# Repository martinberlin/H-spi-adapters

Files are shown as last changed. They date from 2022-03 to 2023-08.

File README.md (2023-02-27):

## Small SPI adapters

H stands for Hardware.

In this repository we will keep PCB designs done in KiCAD for SPI adapters we use. This PCB hardware work uses the [CERN Open Hardware Licence Version 2](https://github.com/martinberlin/H-spi-adapters/blob/master/LICENSE) in the weakly reciprocal version.
Be aware that this is experimental work mostly done for research and **mass-producing this PCB's is not permitted without our written consent**. Fabricating and selling hardware also implies that you need to provide support / fixes and maintain your code examples up to date.

### ESP32-C3 24 pin Good-Display epaper controller with touch

Latest versions of this PCB idea are moved to the [Bistable-smart-switch repository](https://github.com/martinberlin/bistable-smart-switch). Will leave this initial version here for historic reasons.
Along with the 220AC-3.3DC converter with Latch relay this PCB can be used to make a light wall switch but is also great to experiment with SPI epapers and UX design. Here a preview showing front and back Cooper layers plus 3D view:

Fr cu

Back cu

Silkscreen

3D-view

This PCB will be offered only in our [Lectronz store](https://lectronz.com/stores/fasani/). Last unit is available only till end of February 2023.

### UC8156 SPI adapter for Tinypico

Beginning of 2022 I started to learn KiCAD and get more into Hardware. My intention is to help people with their own projects and make new versions, first of existing adapters, to make them smaller and optimize certain things that, I think, could be make better.

My first product in this direction is the [Tinypico SPI adapter for UC8156 displays](https://www.tindie.com/products/fasani/tinypico-small-uc8156-epaper-hat).

uc8156-adapter-small

The supported [displays are sold by German company PlasticLogic](https://www.plasticlogic.com/sampleshop).

## Goodisplay SPI adapter

This is currently being designed. There is a 3 pad's jumper in the PCB, this is what they called RESE option, different epapers might need either the 4.7 soldered to the center, others the 3. If this is wrong selected the epaper might fail to refresh.
Please check what is the right choice for your model downloading the [DESPI-co2 datasheet](https://www.good-display.com/companyfile/DESPI-C02-Specification-29.html).

## Other SPI adapters that might come

Goodisplay Tinypico ESP32 HAT (Idea) In Production, needs revisions from a higher hierarchie ;)

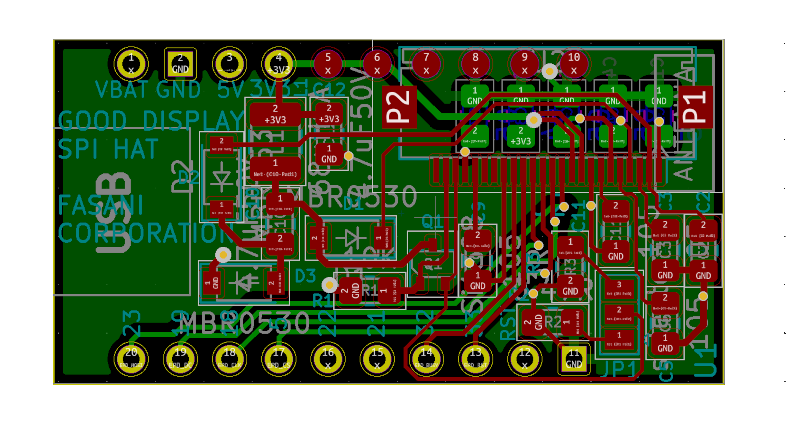
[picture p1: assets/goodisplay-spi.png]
Good display Tinypico HAT


Other epapers.

Intention to make a mini-parallel epaper driver (Will be super hard design)

For more information and currect projects please check:

[https://fasani.de/pcb-design-projects](https://fasani.de/pcb-design-projects)
Most of the PCB's where designed using latest version of KiCAD when writing this lines ( V. 6 )

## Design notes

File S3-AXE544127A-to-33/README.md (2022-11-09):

## Panasonic AXE544127A connector to a 33 pin FPC epaper connector

[AXE544127A](https://app.ultralibrarian.com/details/195de4da-7296-11e9-ab3a-0a3560a4cccc/Panasonic/AXE544127A) to a **XF2M-3315-1A** 33 pin connector which corresponds to 9.7" epaper displays (ED097OC4, ED097TCx and more)

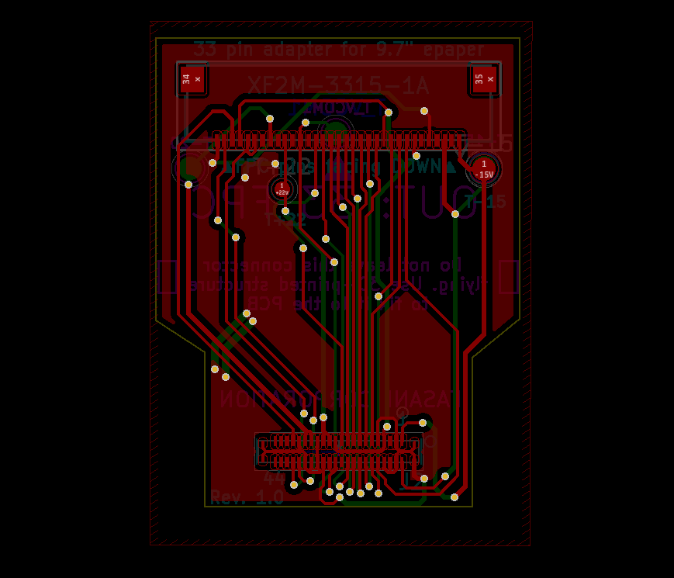
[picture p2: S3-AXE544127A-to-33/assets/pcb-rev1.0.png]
pcb F.Cu


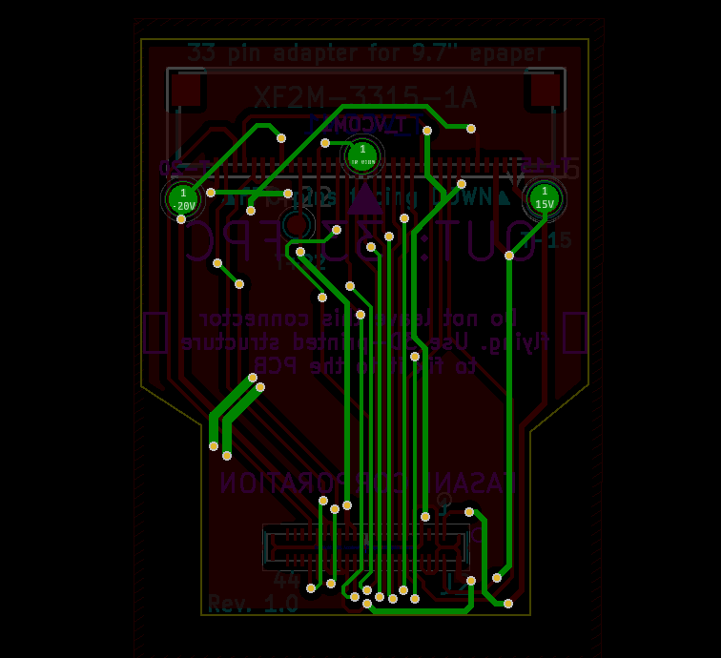
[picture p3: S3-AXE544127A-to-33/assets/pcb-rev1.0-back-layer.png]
pcb Back Cu layer


In short: The aim of this adapter is to use a cheap Lilygo S3 board with all it's hardware additions (RTC, ESP32S3 with fast PSRAM and others) to power a much bigger display than the EPD047.

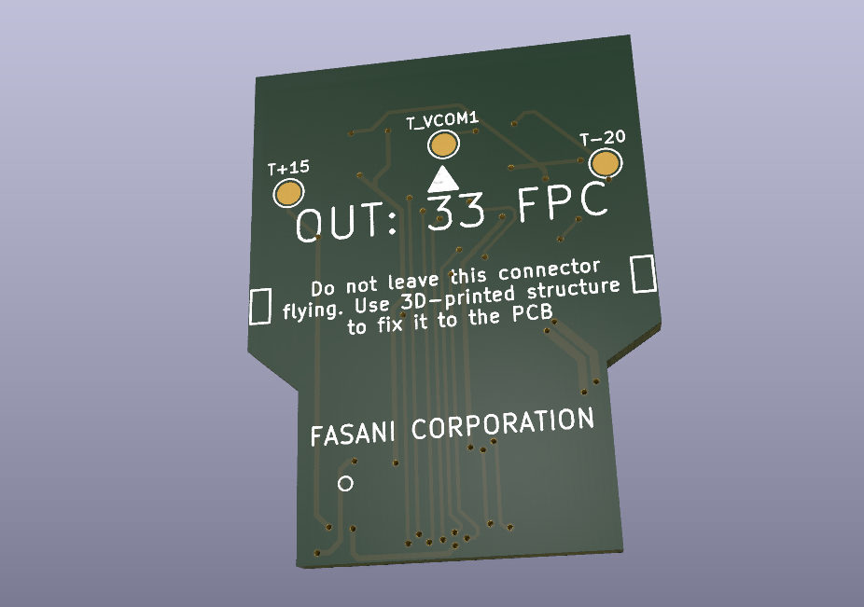
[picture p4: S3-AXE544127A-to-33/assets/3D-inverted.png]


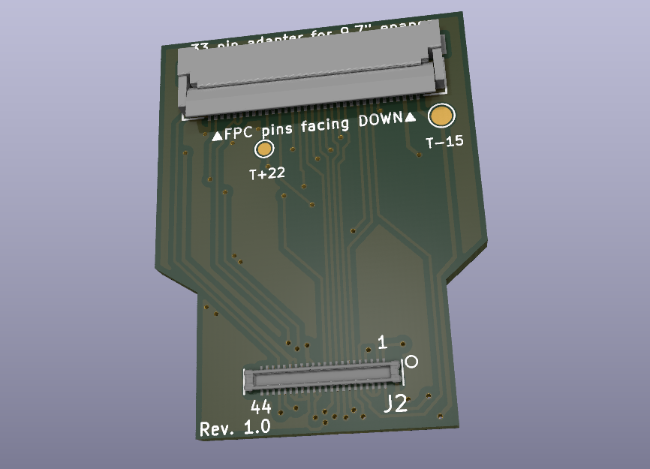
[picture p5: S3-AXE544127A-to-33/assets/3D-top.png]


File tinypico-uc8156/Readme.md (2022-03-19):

### HAT for UC8156 based displays

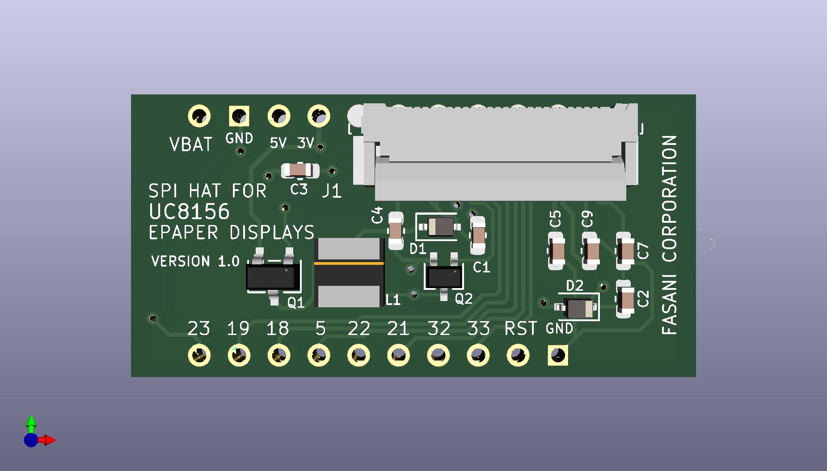
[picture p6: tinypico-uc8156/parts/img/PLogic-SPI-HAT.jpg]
SPI HAT


This small PCB was done as a KiCAD excercise and is still not tested in production. The SPI mini-HAT intention is to fit on the Tinypico.com ESP32 from @tinypico (Unexpected maker) so PlasticLogic very small epapers can be used with minimal wiring.

Designed by Martin Fasani with the help of Paperino_IO and other electronic reviewers.

Thanks to all of them for the help in this small project.

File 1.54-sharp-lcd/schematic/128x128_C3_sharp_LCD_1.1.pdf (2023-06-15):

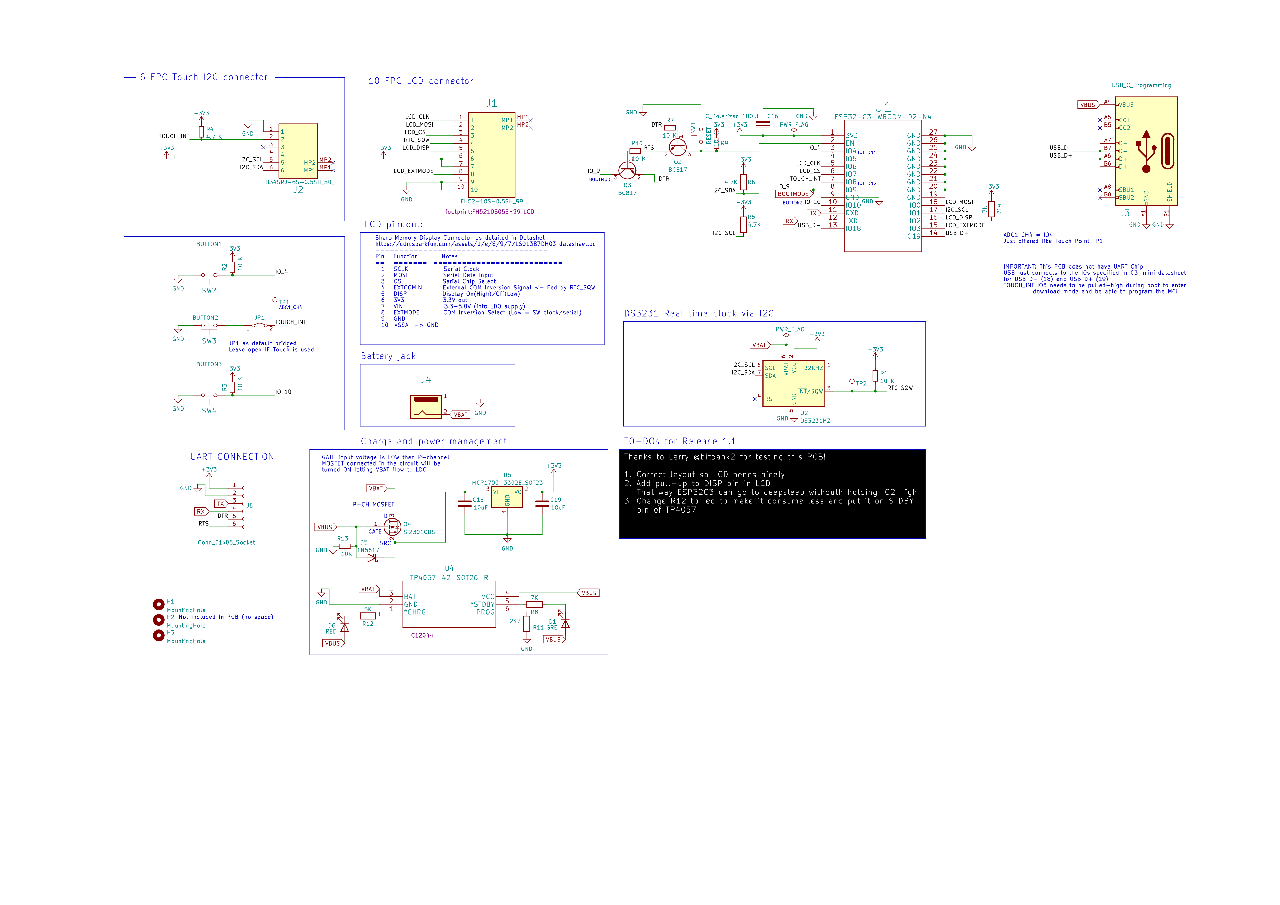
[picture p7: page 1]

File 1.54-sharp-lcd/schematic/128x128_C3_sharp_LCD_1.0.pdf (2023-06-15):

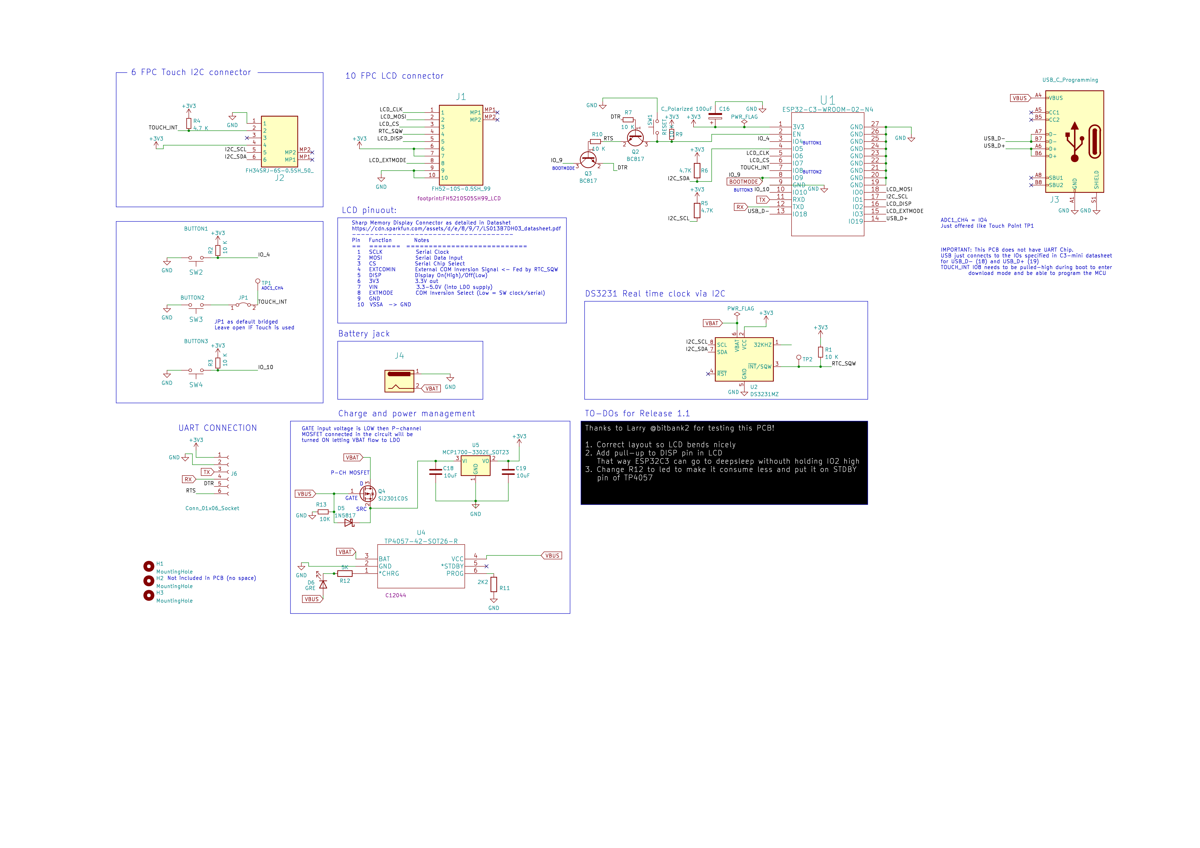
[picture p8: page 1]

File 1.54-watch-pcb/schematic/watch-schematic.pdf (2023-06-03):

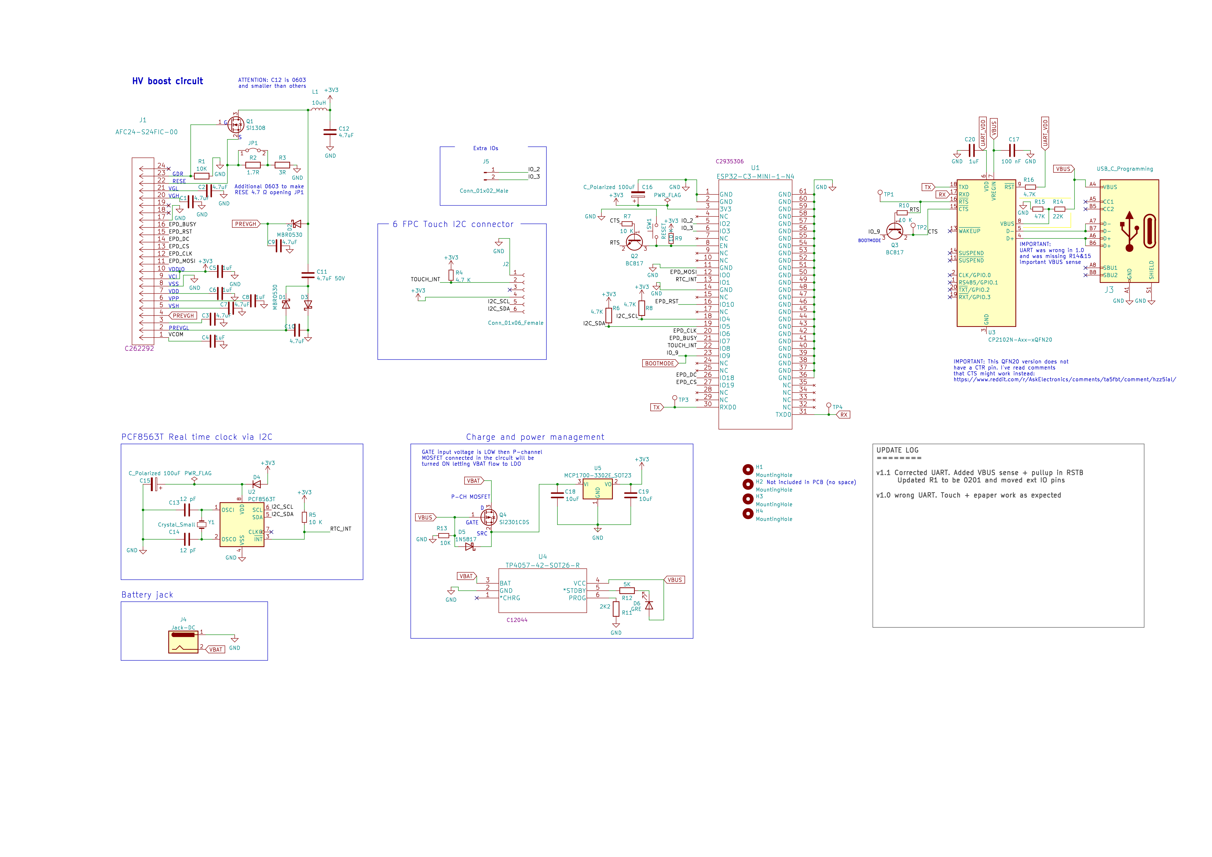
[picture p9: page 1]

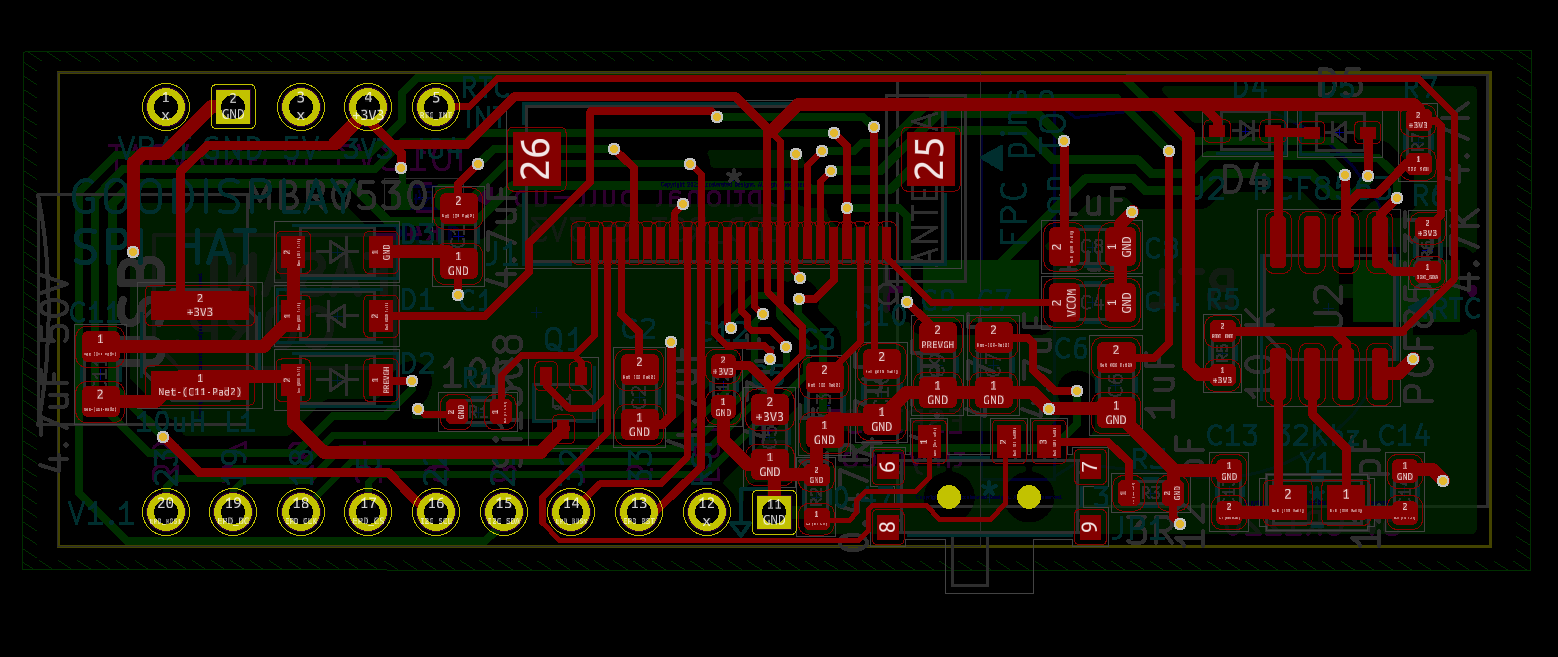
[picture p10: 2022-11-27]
tinypico-goodisplay/schematic/PCB-routing-tinypico-GD.png

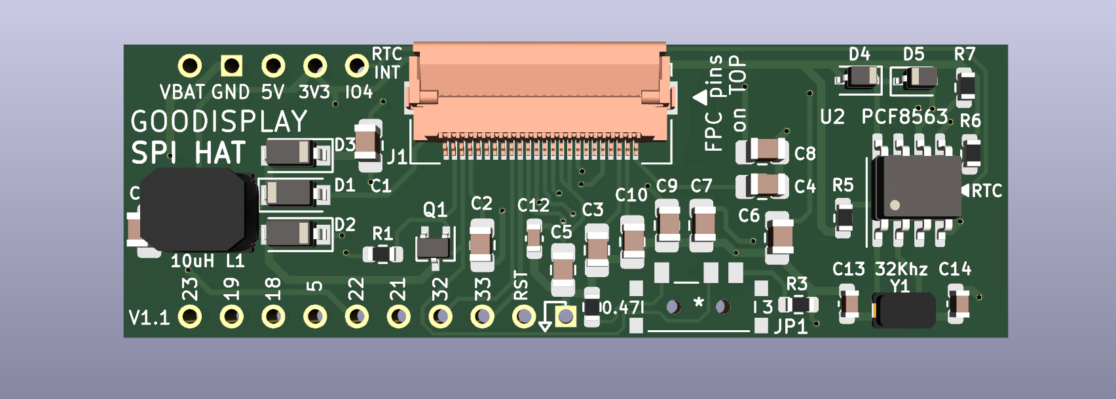
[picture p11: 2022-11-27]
tinypico-goodisplay/schematic/PCB-front.png

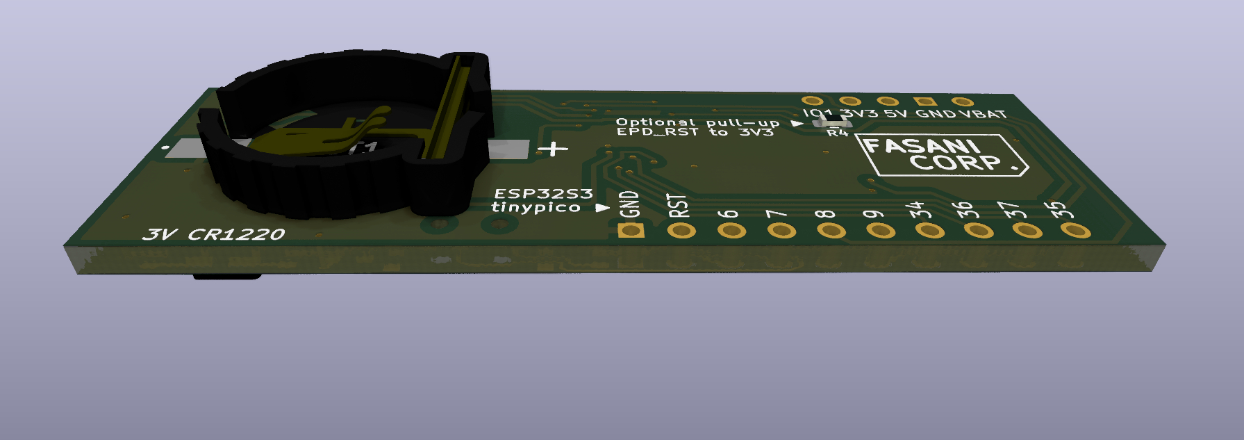
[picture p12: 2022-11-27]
tinypico-goodisplay/schematic/PCB-back.png

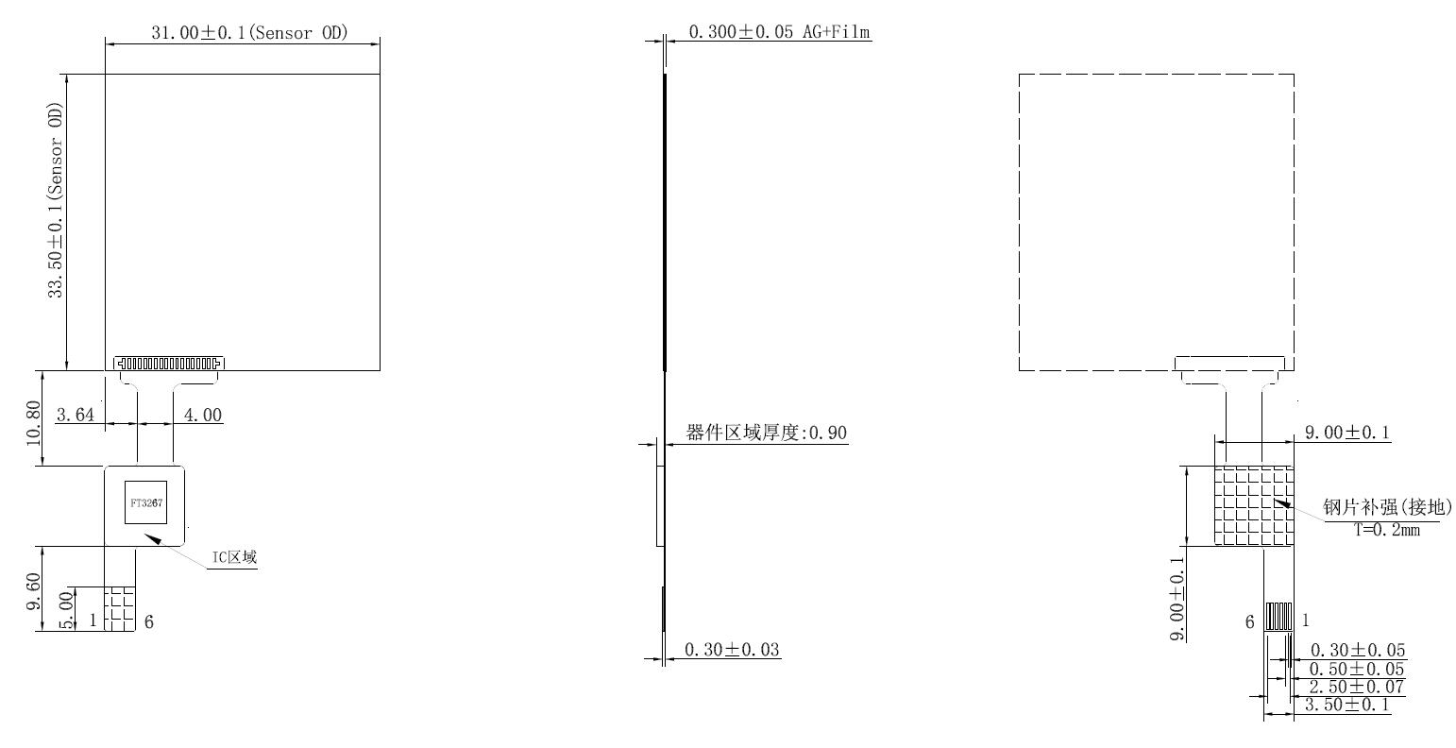
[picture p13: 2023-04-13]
1.54-sharp-lcd/schematic/EPD_drawing/200x200_FT_touch.jpg

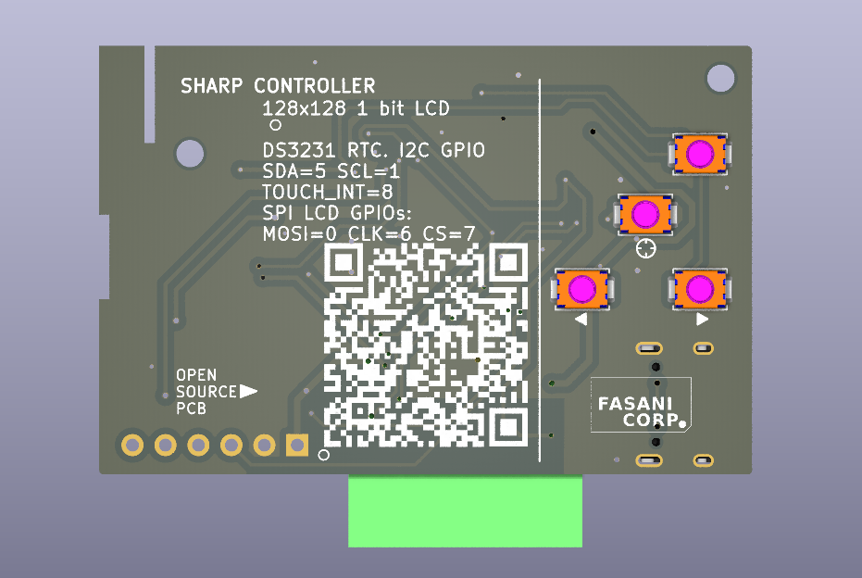
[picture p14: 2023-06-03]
1.54-sharp-lcd/schematic/sharp-lcd-front.png

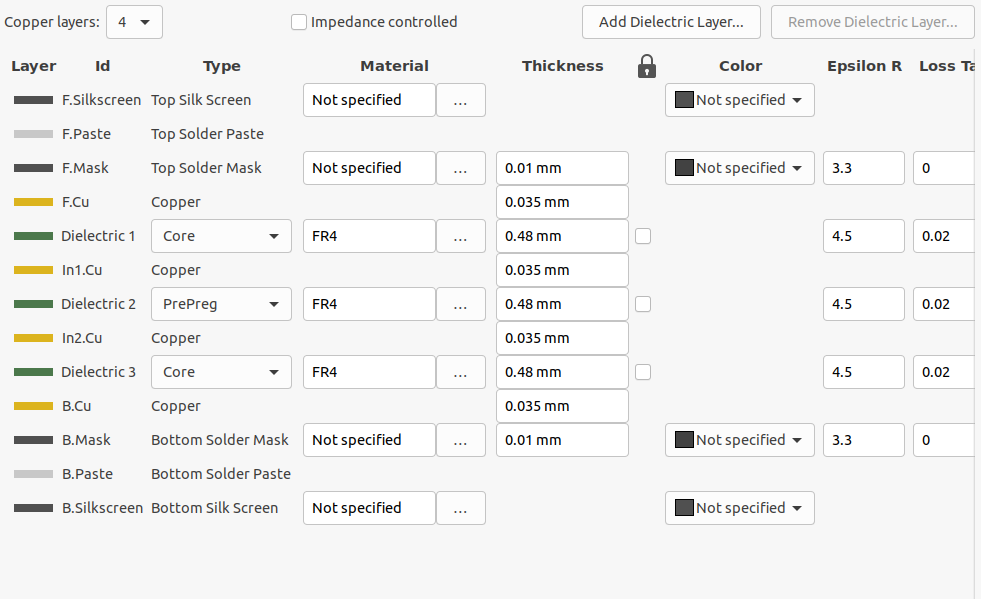
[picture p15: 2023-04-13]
1.54-watch-pcb/schematic/EPD_drawing/PCB-4--Layer-stockup.png

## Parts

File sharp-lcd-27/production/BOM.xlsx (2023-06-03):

Designator | Footprint | Comment | JLPCB Part#
R2,R10,R9,R7,R1 | R_0603_1608Metric | 10 K | C25804
U1 | ESP32-C3-WROOM-02-N4 | ESP32-C3-WROOM-02-N4 | C2934560
Q2,Q3 | SOT-23 | BC817 | C146798
R13 | R_0603_1608Metric | 10K | C25804
C18,C19 | C_0805_2012Metric | 10uF | C15850
R4 | R_0603_1608Metric | 4.7 K | C23162
U5 | SOT-23 | MCP1700-3302E_SOT23 | C39051
D6 | LED_0805_2012Metric | GRE | C2297
U2 | SOIC-8_3.9x4.9mm_P1.27mm | DS3231MZ | C107410
U4 | TP4057-42-SOT26-R | TP4057-42-SOT26-R | C12044
Q4 | SOT-23 | Si2301CDS | C10487
J3 | USB_C_Receptacle_HRO_TYPE-C-31-M-12 | USB_C_Programming | C165948
D5 | D_SOD-323 | 1N5817 | C191023
C16 | CP_EIA-3528-21_Kemet-B | C_Polarized 100uF | C129289
R8,R6 | R_0603_1608Metric | 4.7K | C23162
J2 | FH34SRJ-6S-0.5SH50-Hirose | FH34SRJ-6S-0.5SH_50_ | C224194
J1 | FH5210S05SH99_LCD | FH52-10S-0.5SH_99 | C598038
R11 | R_0805_2012Metric | 2K2 | C17520
R12 | R_0603_1608Metric | 5K | C23046

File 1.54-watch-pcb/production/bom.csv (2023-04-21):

Id | Designator | Footprint | Quantity | Designation | Supplier and ref
1 | C4,C6,C5,C8 | C_0805_2012Metric_Pad1.18x1.45mm_HandSolder | 4 | 1uF
2 | Q4 | SOT-23 | 1 | Si2301CDS
3 | R2 | R_0603_1608Metric | 1 | 1.7R
4 | C18,C19 | C_0805_2012Metric | 2 | 10uF
5 | TP4,TP1,TP2,TP3 | TestPoint_Pad_1.0x1.0mm | 4 | 32Khz
6 | R9,R7,R10,R5 | R_0603_1608Metric | 4 | 10 K
7 | C13,C14 | C_0603_1608Metric | 2 | 12 pF
8 | J1 | AFC24-S24FIC-00 | 1 | AFC24-S24FIC-00
9 | L1 | SWPA4030S1R0NT | 1 | 10uH
10 | R6,R8 | R_0603_1608Metric | 2 | 4.7K
11 | U1 | ESP32-C3-MINI-1-N4 | 1 | ESP32-C3-MINI-1-N4
12 | D5 | D_SOD-123 | 1 | 1N5817
13 | J5 | PinHeader_1x02_P1.27mm_Vertical | 1 | Conn_01x02_Male
14 | D6 | LED_0805_2012Metric | 1 | GRE
15 | R1,R13 | R_0603_1608Metric | 2 | 10K
16 | C7,C10,C9,C3,C2,C1 | C_0805_2012Metric_Pad1.18x1.45mm_HandSolder | 6 | 4.7uF
17 | U2 | SOIC-8_3.9x4.9mm_P1.27mm | 1 | PCF8563T
18 | Q3,Q2 | SOT-23 | 2 | BC817
19 | J3 | USB_C_Receptacle_HRO_TYPE-C-31-M-12 | 1 | USB_C_Programming
20 | D4 | D_SOD-323 | 1 | 1N4148WS
21 | Y1 | Q13FC1350000400-Crystal | 1 | Crystal_Small
22 | R3 | R_0603_1608Metric | 1 | 3R
23 | D3,D1,D2 | D_SOD-123 | 3 | MBR0530
24 | C17 | C_0805_2012Metric | 1 | 100 nF
25 | Q1 | SOT-323_SC-70 | 1 | Si1308
26 | C15,C16 | CP_EIA-3528-21_Kemet-B | 2 | C_Polarized 100uF
27 | C12 | C_0603_1608Metric | 1 | 4.7uF
28 | U5 | SOT-23 | 1 | MCP1700-3302E_SOT23
29 | R4 | R_0603_1608Metric | 1 | 4.7 K
30 | J2 | FH34SRJ-6S-0.5SH50-Hirose | 1 | Conn_01x06_Female
31 | R11 | R_0805_2012Metric | 1 | 2K2
32 | J4 | JST_ACH_BM02B-ACHSS-GAN-ETF_1x02-1MP_P1.20mm_Vertical | 1 | Jack-DC
33 | R12 | R_0603_1608Metric | 1 | 5K
34 | U3 | CP2102NA02GQFN20 | 1 | CP2102N-Axx-xQFN20
35 | C11 | C_0805_2012Metric_Pad1.18x1.45mm_HandSolder | 1 | 4.7uF 50V
36 | U4 | TP4057-42-SOT26-R | 1 | TP4057-42-SOT26-R
37 | JP1 | SolderJumper-2_P1.3mm_Bridged_RoundedPad1.0x1.5mm | 1 | Jumper_2_Bridged
38 | SW1 | Alps_SKRK | 1 | RESET

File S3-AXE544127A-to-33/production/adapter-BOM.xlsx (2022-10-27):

Designator | Footprint | Comment | JLPCB Part#
J1 | CONN_ED097OC4 | XF2M-3315-1A | C231420
J2 | AXE644224A | CONN_AXE644124A_PAN | C5200801

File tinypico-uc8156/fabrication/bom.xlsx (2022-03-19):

Designator | Footprint | Comment | JLPCB Part#
C3,C9,C5,C4 | 0603 | 1µ 25V | C307478
J1 | TE_2-1734839-6_1x26-1MP_P0.5mm_Horizontal | Bottom contact FPC | C262568
C1,C2 | 0603 | 2µ2 35V | C57895
L1 | 1210 | 47µ | C223059
D1,D2 | D_SOD-323 | D_Schottky | C154819
C7 | 0603 | 100n 16V | C307478
Q2 | SOT-323 | MOSFET N-CH 30V 1.4A SC-70-3 | C469327
Q1 | SOT-23-3 | FET P-CH 60V 620Ma | C534588

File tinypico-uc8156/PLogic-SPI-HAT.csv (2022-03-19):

Source: | /home/martin/Documents/kicad/M5StampC3-martin-mod/KICAD-PlasticLogic/PLogic-SPI-HAT.kicad_sch
Date: | Mon 10 Jan 2022 13:32:43 CET
Tool: | Eeschema 6.0.0-d3dd2cf0fa~116~ubuntu20.04.1
Generator: | /usr/share/kicad/plugins/bom_csv_grouped_by_value_with_fp.py
Component Count: | 13
Ref | Qnty | Value | Cmp name | Footprint | Description | Vendor
C1, C2, | 2 | 2µ2 35V | C | Capacitor_SMD:C_0603_1608Metric
C3, C4, C7, C9, | 4 | 1µ 25V | C | Capacitor_SMD:C_0603_1608Metric
C5, | 1 | 100µ 16V | C | Capacitor_SMD:C_0603_1608Metric
D1, D2, | 2 | D_Schottky | D_Schottky | Diode_SMD:D_SOD-323
L1, | 1 | 47µ | 82473C | digikey-footprints:1210
Q1, | 1 | FET P-CH 60V 620Ma | FQP27P06 | digikey-footprints:TO-220-3
Q2, | 1 | FET N-CH 30V 1.4A | ZXM61N03F | Package_TO_SOT_SMD:SOT-23
U1, | 1 | Connector2_FPCConn | Connector2_FPCConn | Connector_FFC-FPC:TE_2-1734839-4_1x24-1MP_P0.5mm_Horizontal

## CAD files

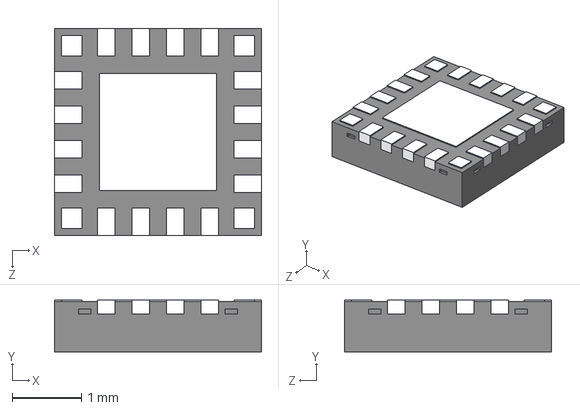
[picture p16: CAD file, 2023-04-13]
1.54-watch-pcb/parts/3d/CP2102N-A01-GQFN20R.step
3.00 x 0.75 x 3.00 mm

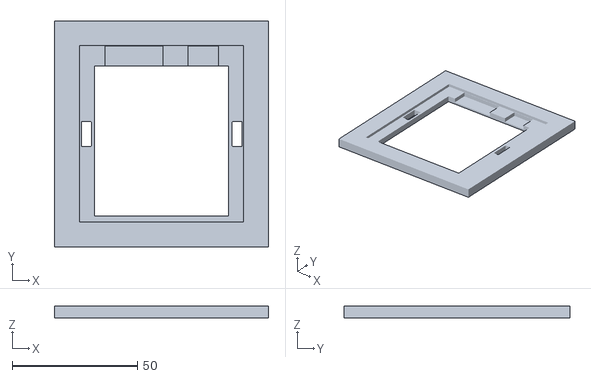
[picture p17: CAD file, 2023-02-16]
C3-27-epaper-touch/3D/case-switch-epaper.stl
85.5 x 90.2 x 4.73

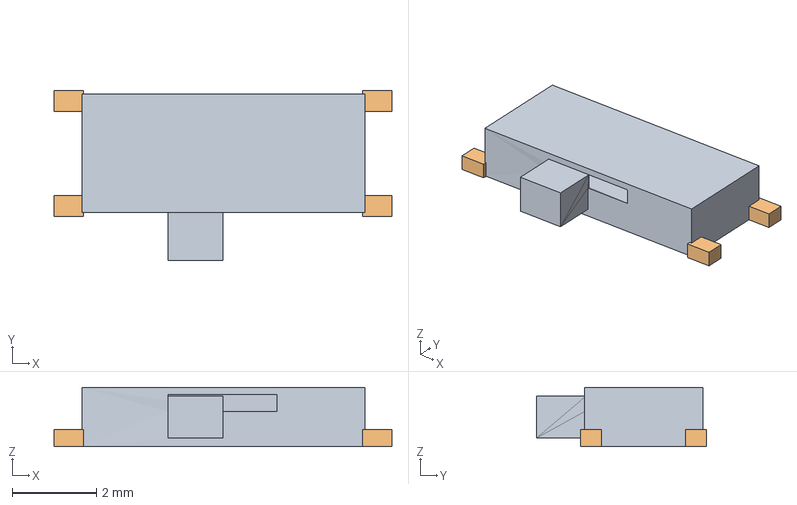
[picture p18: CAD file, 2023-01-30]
C3-27-epaper-touch/parts/3d/MK-12C02-G015.step
8.01 x 4.03 x 1.40 mm

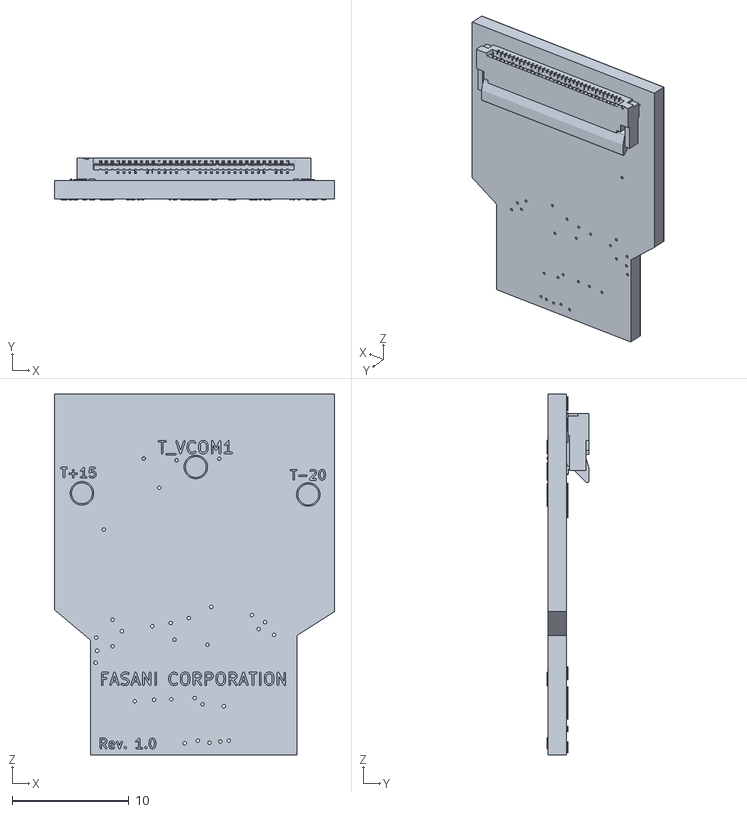
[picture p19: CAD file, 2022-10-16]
S3-AXE544127A-to-33/assets/adapter-Lilygo-3D.stl
24.0 x 3.58 x 30.9

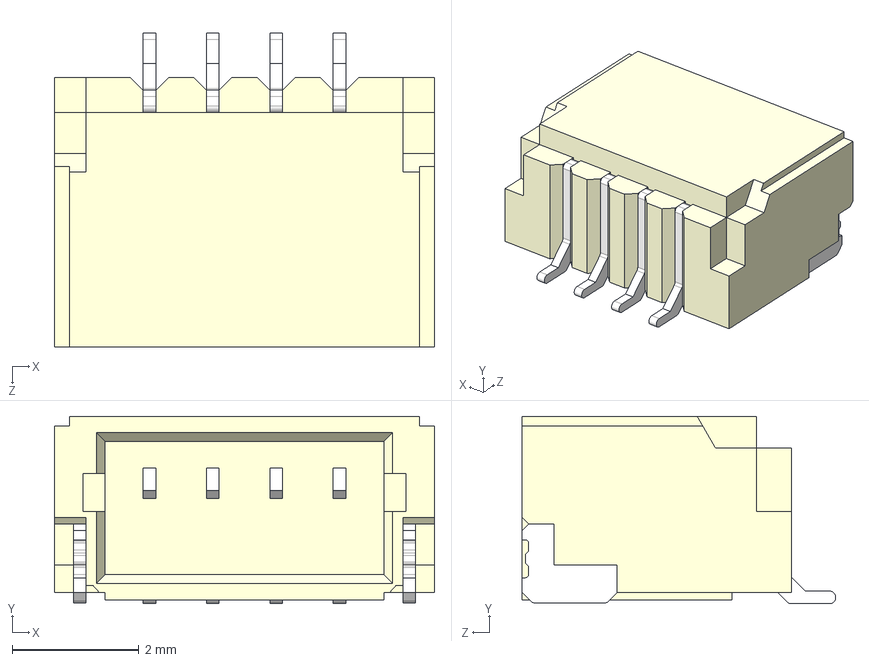
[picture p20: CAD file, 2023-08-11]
sharp-lcd-27/parts/3d/PRT-14417-qwiic.step
6.00 x 2.96 x 4.95 mm

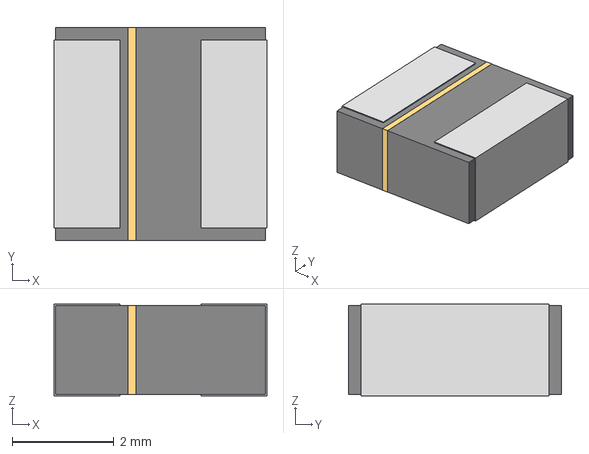
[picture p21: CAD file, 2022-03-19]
tinypico-uc8156/parts/3d/IND_TAIYO_NR4018_TAY.step
4.19 x 4.20 x 1.80 mm

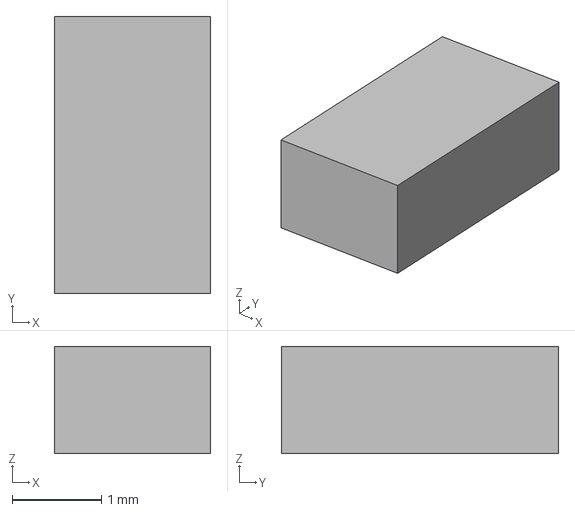
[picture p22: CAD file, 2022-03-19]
tinypico-uc8156/parts/eec.models/Infineon_-_BSR315P.step
1.75 x 3.10 x 1.20 mm

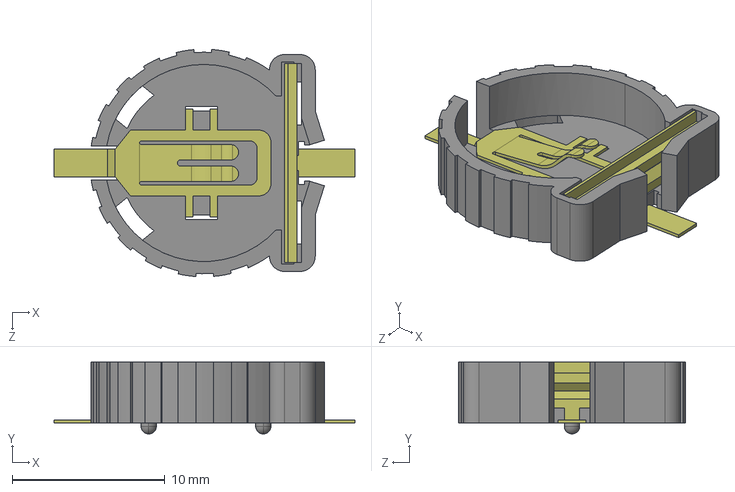
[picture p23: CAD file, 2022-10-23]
1.54-watch-pcb/parts/3d/CR1220-2.step
19.7 x 4.70 x 14.9 mm

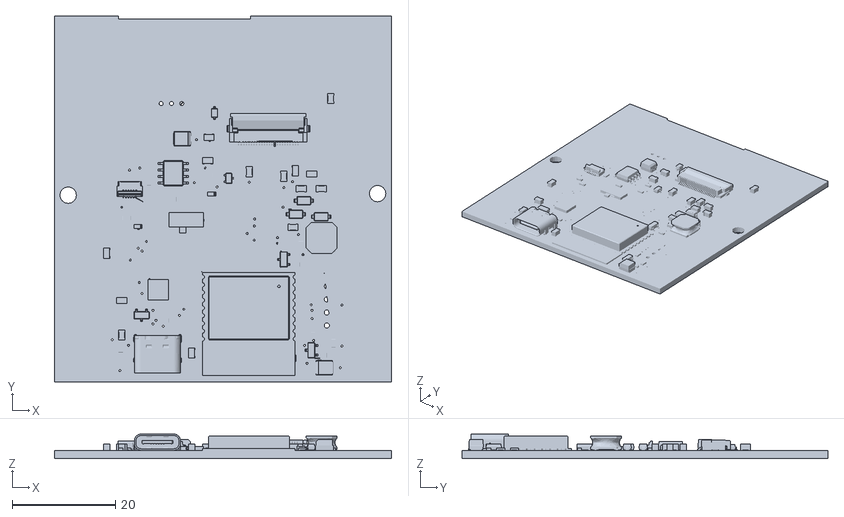
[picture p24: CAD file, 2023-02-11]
C3-27-epaper-touch/3D/C3-27-epaper-touch-3D.stl
65.4 x 71.0 x 4.84

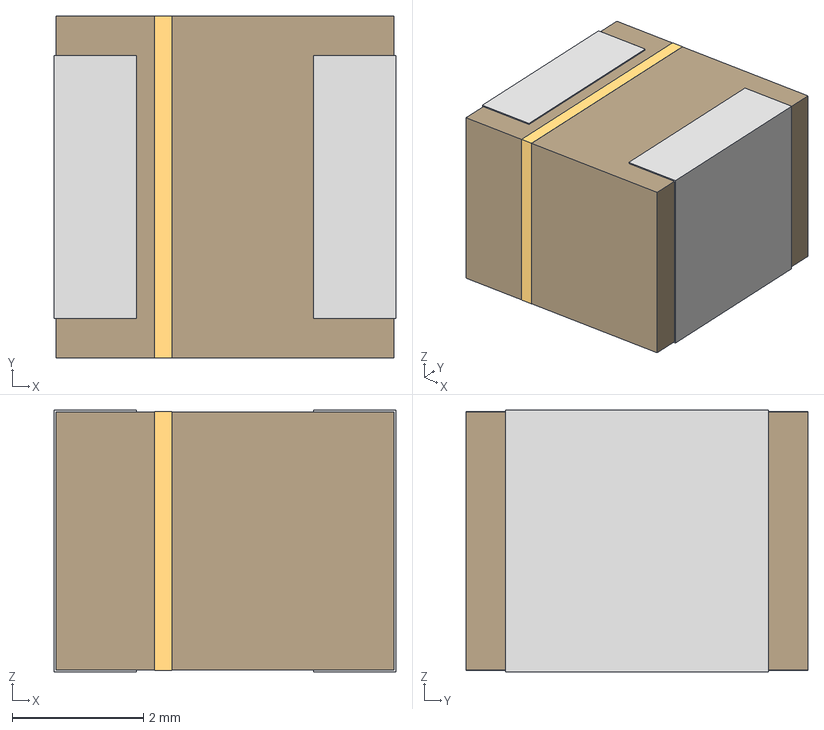
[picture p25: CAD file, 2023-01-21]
C3-27-epaper-touch/parts/3d/IND_0S282MT_SNL.step
5.21 x 5.21 x 3.99 mm

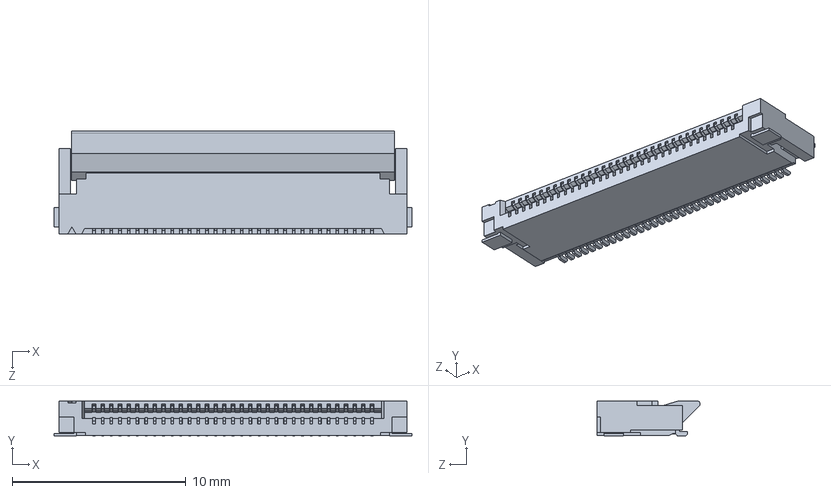
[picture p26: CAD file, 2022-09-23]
S3-AXE544127A-to-33/component/XF2M_3315_1A.step
20.6 x 2.00 x 5.90 mm

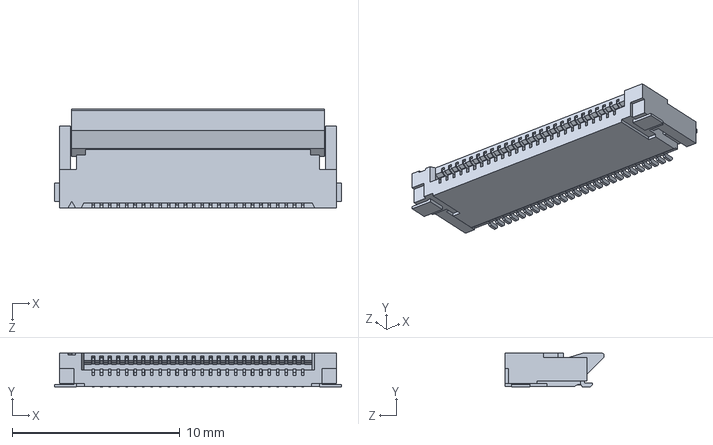
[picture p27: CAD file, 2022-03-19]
tinypico-uc8156/parts/3d/XF2M_2615_1A.step
17.1 x 2.00 x 5.90 mm

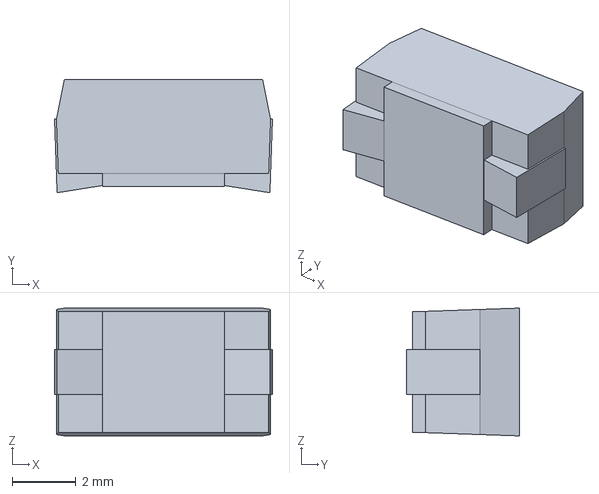
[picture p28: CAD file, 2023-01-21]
C3-27-epaper-touch/parts/3d/c-5-1676966-1-ba-3d.stp
6.82 x 3.55 x 4.00 mm

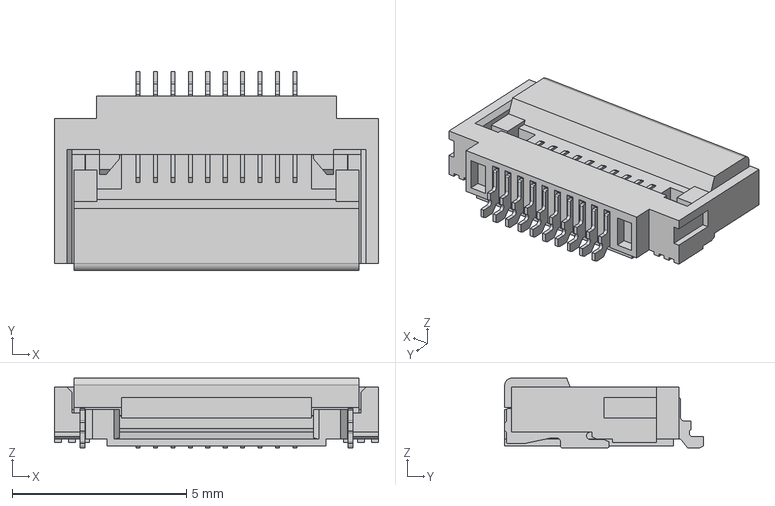
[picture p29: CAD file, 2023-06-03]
sharp-lcd-27/parts/3d/LCD-10S-0.5SH.step
9.30 x 5.70 x 2.00 mm

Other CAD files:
tinypico-uc8156/parts/3d/MOSFET_8EDL-T1-GE3_VIS.step
sharp-lcd-27/parts/3d/Button_SKRKAH.step
C3-27-epaper-touch/parts/3d/0443Series_LTF.step
C3-27-epaper-touch/parts/3d/AP22802AW5-7.step
S3-AXE544127A-to-33/component/axe644124.stp
sharp-lcd-27/parts/3d/ESP32-C3-WROOM-02-H4.step
sharp-lcd-27/parts/3d/FH12-24S-0.5SH_55_.step
sharp-lcd-27/parts/3d/FH34SRJ-6S-0.5SH50-Hirose.step
sharp-lcd-27/parts/3d/L-40xx.STEP
sharp-lcd-27/parts/3d/TP4057-SOT-23.step
sharp-lcd-27/parts/3d/USB_TYPE-C-31-M-12.step

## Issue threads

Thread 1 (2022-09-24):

Adapter: Liygo AXE544127A connector to a 33 pin FPC epaper connector

martinberlin, 2022-09-24:
In directory:
https://github.com/martinberlin/H-spi-adapters/tree/master/S3-AXE544127A-to-33

Images:
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

martinberlin, 2022-12-15:
Closing here: It works but I'm not going to fabricate it anymore

Closed 2022-12-15.

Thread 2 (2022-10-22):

Tinypico Goodisplay SPI HAT with RTC

martinberlin, 2022-10-22:
Make a variation adding small and cheap PCF8563 RTC chip and crystal
branch: **2/rtc**

Last task pending:

- [x] Add SPI labeling in Silkscreen (SI, CLK, CS, DC)

martinberlin, 2023-02-07:
Done and working correctly.
Please consider getting one here:
https://lectronz.com/stores/fasani/
In order to support our work.

Closed 2023-02-07.

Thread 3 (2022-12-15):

220 AC to 3.3 VDC adapter for SPI epapers

martinberlin, 2022-12-15:
First sample will be focused just on getting the alternate current into estable 3.3V

- [x] Check the Schematics and get it approved by Carlos F.
- [x] Make the smallest possible design but passing all DRCs

New Tasks added after some feedback in Twitter (Thanks Rico, Larry and others)

- [ ] **1** Add an [optocoupler](https://www.jameco.com/Jameco/workshop/Howitworks/what-is-an-optocoupler-and-how-it-works.html) to know if the lamp is on
- [ ] **2** Add 2 [WHITE](https://jlcpcb.com/partdetail/Worldsemi-WS2812B_BW/C2761795) Leds (Or RGBW)

### Tech notes

1. Latch relay has no way to return if it's ON or OFF) This will also enable some smart behavior like not to count consumption if the light is circuit is not closed (Light is broken for example)
2. For this to happen, we should update the 220AC converter to output 5V instead of 3.3V since otherwise the voltage will be too low for the 2812's (At least in datasheet min. Volts are 3.7 V and it's a known fact that Blue and White need more voltage than the others)

Important and to be considered: With the [ESP32C3](https://www.espressif.com/sites/default/files/documentation/esp32-c3-wroom-02_datasheet_en.pdf) small MCU we use there are only 2 GPIOS left. Adding this two we don't any more available which kind of limits possibilities if you would like to control a second thing in the same epaper UX (2nd latch or simple relay)

martinberlin, 2023-01-27:
Done. Both PCBs are working but will leave open until last release is for sale

Leone25, 2023-01-31:
Serious question, shouldn't there be no ground near the switch input? The ground plane under the relay input are kind of messing up the galvanic isolation ...
current:
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
to something like:
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
Also since there is the space it might be a good idea to increase the trace size of the switched ac side? I know it is limited by the relay anyway but less resistance is better.

martinberlin, 2023-01-31:
Sure that is a great catch. GND pane there can be dangerous and it's not really needed at all.
The traces are 1 mm. You think 1.5 or 2 mm would be better, then we can update it, no problem.

martinberlin, 2023-02-13:
Point 1 might be implemented in next Release. Leds for the moment not.
A more elegant solution would be to have a front-light LED layer over the epaper.

Closed 2023-02-13.

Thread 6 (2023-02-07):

Mini 1.54" watch PCB with touch support

martinberlin, 2023-02-07:
The new idea for a PCB is to get as tiny as possible having the already existing Tinypico controller but using instead:

- DS3231MZ (LCSC part C107410) guess without backup battery since there will be no space
- Cheap version 1.0 with PCF8563T instead and a 100 nF Tantalium Capacitor as backup power source (No temperature)
- Touch connector 6 FPC (Mind [right ones](https://github.com/martinberlin/FT6X36-IDF))
- Mini battery charger TP4057

[Schematics](https://github.com/martinberlin/H-spi-adapters/blob/6/watch/1.54-watch-pcb/schematic/watch-schematic.pdf) starting to take form.

In Branch: https://github.com/martinberlin/H-spi-adapters/tree/6/watch
Directory [1.54-watch-pcb](https://github.com/martinberlin/H-spi-adapters/tree/6/watch/1.54-watch-pcb)

martinberlin, 2023-04-21:
First release v1.0 sent to fabrication. Check the nice review in #9

Closed 2023-08-09.

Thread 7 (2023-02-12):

ESP32-C3 24 pinn FPC epaper controller with touch Rel 1.1 review

martinberlin, 2023-02-12:
The goal of this issue is an effective PCB review by GOOD DISPLAY and by independent interested parties. All KiCAD files can be found here:
https://github.com/martinberlin/H-spi-adapters/tree/master/C3-27-epaper-touch

For any other PCB creations I will make sure to check the bootloader and other important MCU design guidelines (This costed me a failed Rev 1.0)
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

**Other important notes and pin configurations:**

1. Touch INT is also shared w/ IO8 which needs to be high in order for MCU to enter download mode. (So it needs to have a 3.x K resistor or you can't flash it, otherwise I will put a 10K resistor but it won't work)
2. RTC INT alarm output is also offered as an external GPIO with the advice that is RTC INT and has a 10K pullup resistor.

PCB Preview in front copper and back, plus silkscreen and front 3D view (has only 2 layers to make it cheaper)

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

martinberlin, 2023-04-21:
Working. NOTE: This project stays here for historical reasons but now the switch idea has it's own repository
https://github.com/martinberlin/bistable-smart-switch/

Closed 2023-04-21.

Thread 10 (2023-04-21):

10 - Idea for a mini PCB for 128x128 Sharp memory LCD

martinberlin, 2023-04-21:
This is more like a challenge than a real PCB that goes to fabrication.
I like a lot this [small Sharp LCDs](https://twitter.com/martinfasani/status/1645877484418736128) since they have a great refresh rate compared to epaper displays. So here is the challenge:

To build a small watch PCB with following constraints / features:

- Not much bigger than the display itself 32 x 37.4 mm max.
- No UART chip this time, but the USB-C will be connected to the data pins of MCU (JTAG interface)
- DS3231Mz RTC
- TP4057🔋 charger
- 10 pin connector for LCD
- 6 pin FPC for touch (optional)
- MCU (not sure what one yet) would prefer one that has at least 2MB external RAM so you can use LVGL

Note: That the Sharp LCD does not have touch. I will use one 1.54" FTxxx from GoodDisplay driven by my own fork:
https://github.com/martinberlin/FT6X36-IDF

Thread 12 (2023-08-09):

2.7" 240x400 SHARP Memory LCD

martinberlin, 2023-08-09:
Need to make a variation from the current [128x128 PCB](/martinberlin/H-spi-adapters/tree/master/1.54-sharp-lcd)
The 2.7" needs:

- To be powered at least by >= **3.7 Volts** in VCC (Either VBAT or VUSB)
- Adapted so the touch panel of [2.7" FT6xx36 of Good display](https://twitter.com/martinfasani/status/1689201632532140032?s=20) matches, or check for a 2.7" touch that is sold separately
- PCB needs to be exactly 65x45 mm in the external touch size that is about 1 mm bigger than the LCD

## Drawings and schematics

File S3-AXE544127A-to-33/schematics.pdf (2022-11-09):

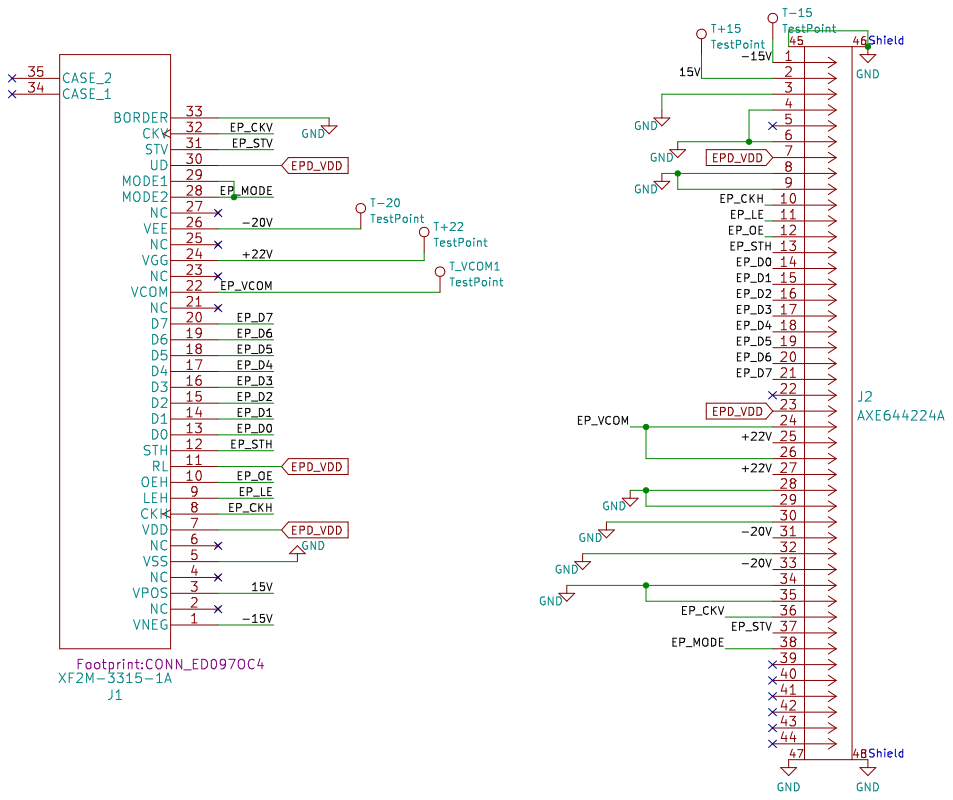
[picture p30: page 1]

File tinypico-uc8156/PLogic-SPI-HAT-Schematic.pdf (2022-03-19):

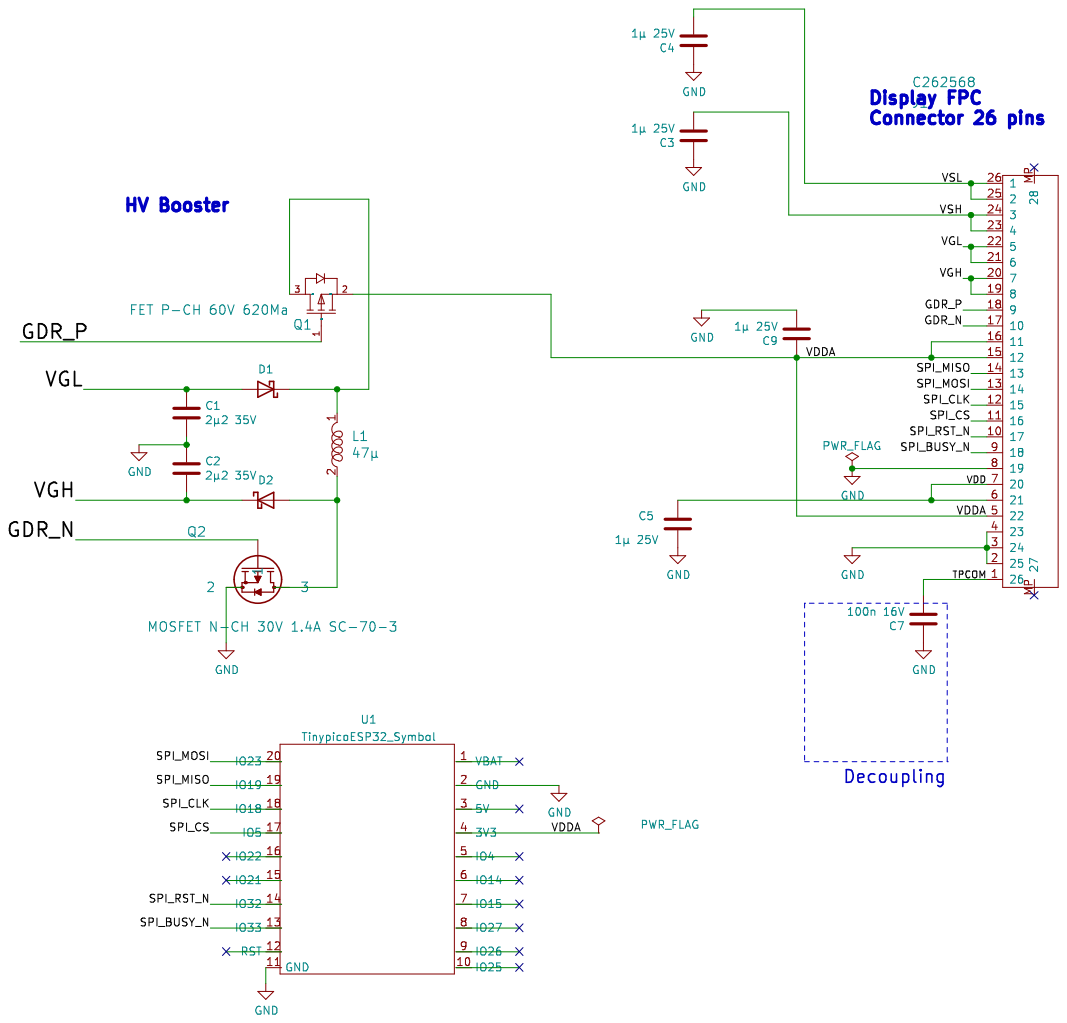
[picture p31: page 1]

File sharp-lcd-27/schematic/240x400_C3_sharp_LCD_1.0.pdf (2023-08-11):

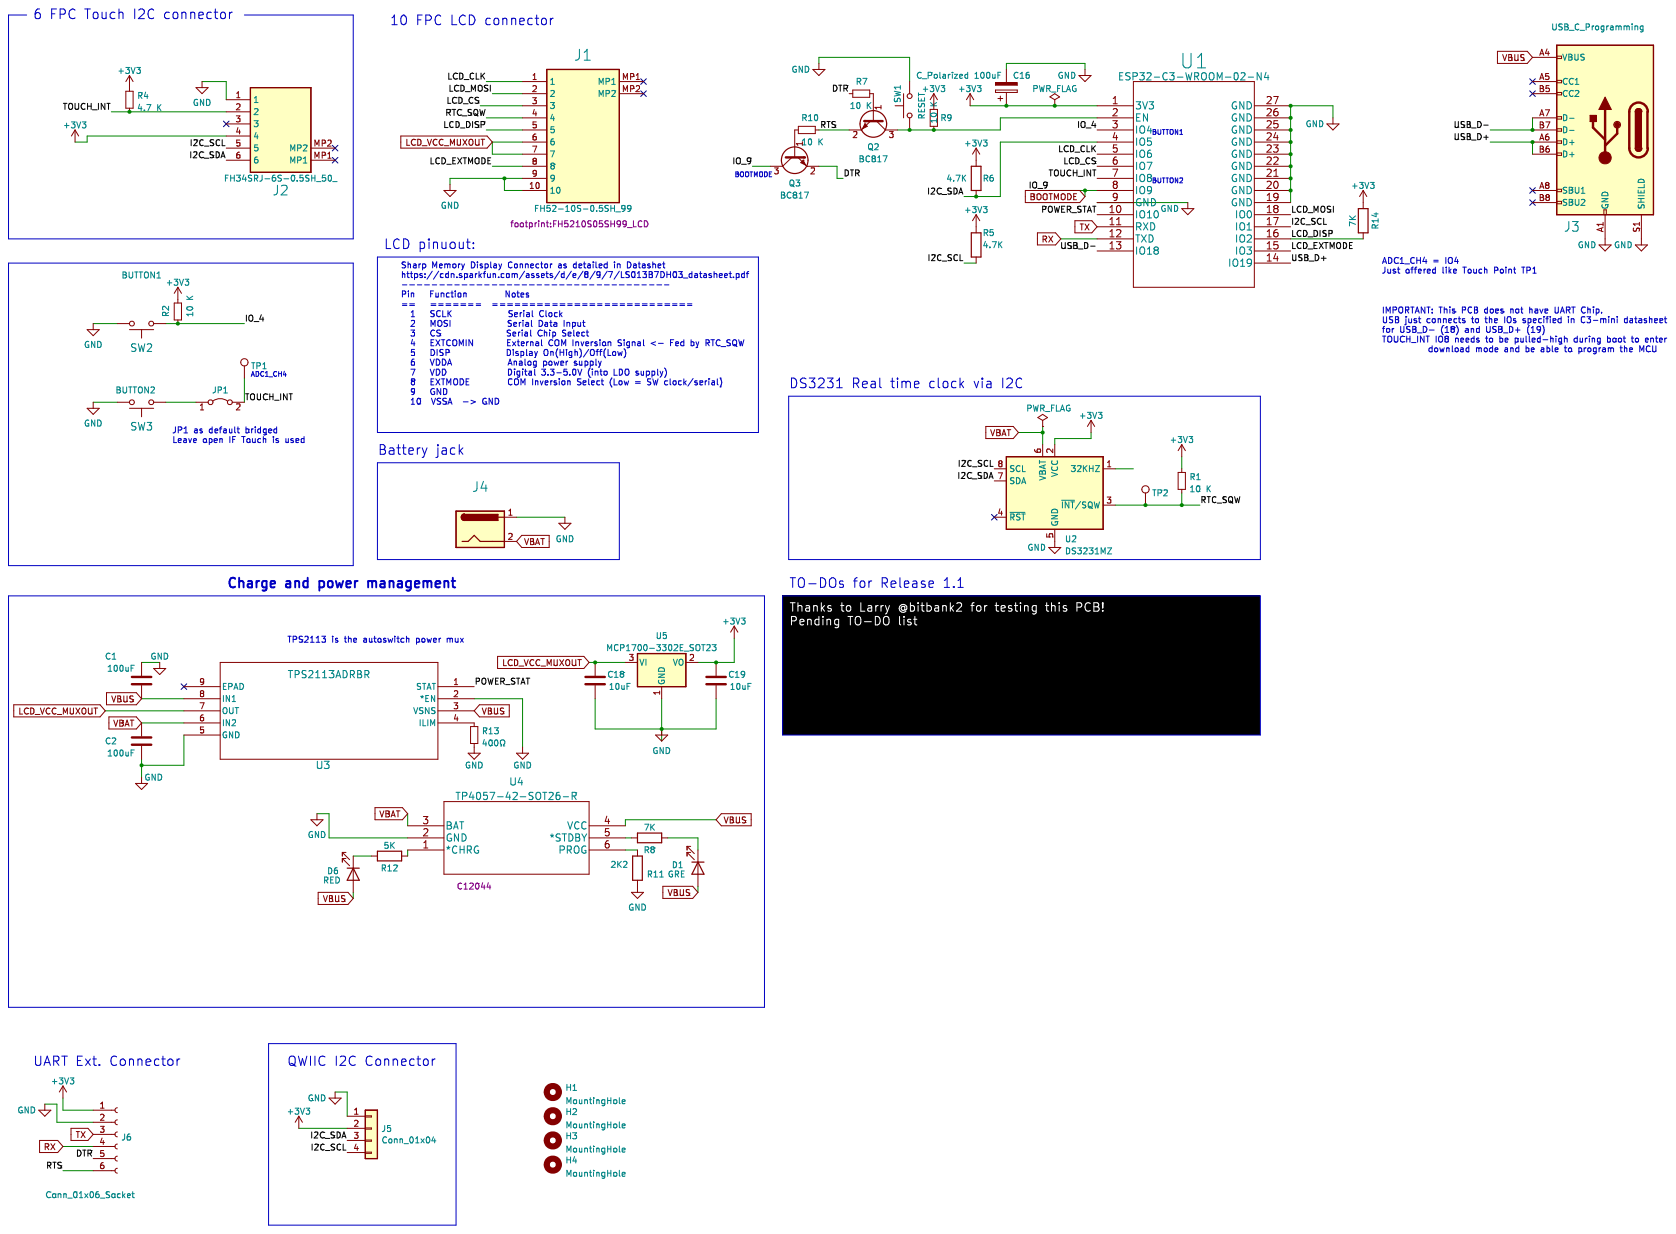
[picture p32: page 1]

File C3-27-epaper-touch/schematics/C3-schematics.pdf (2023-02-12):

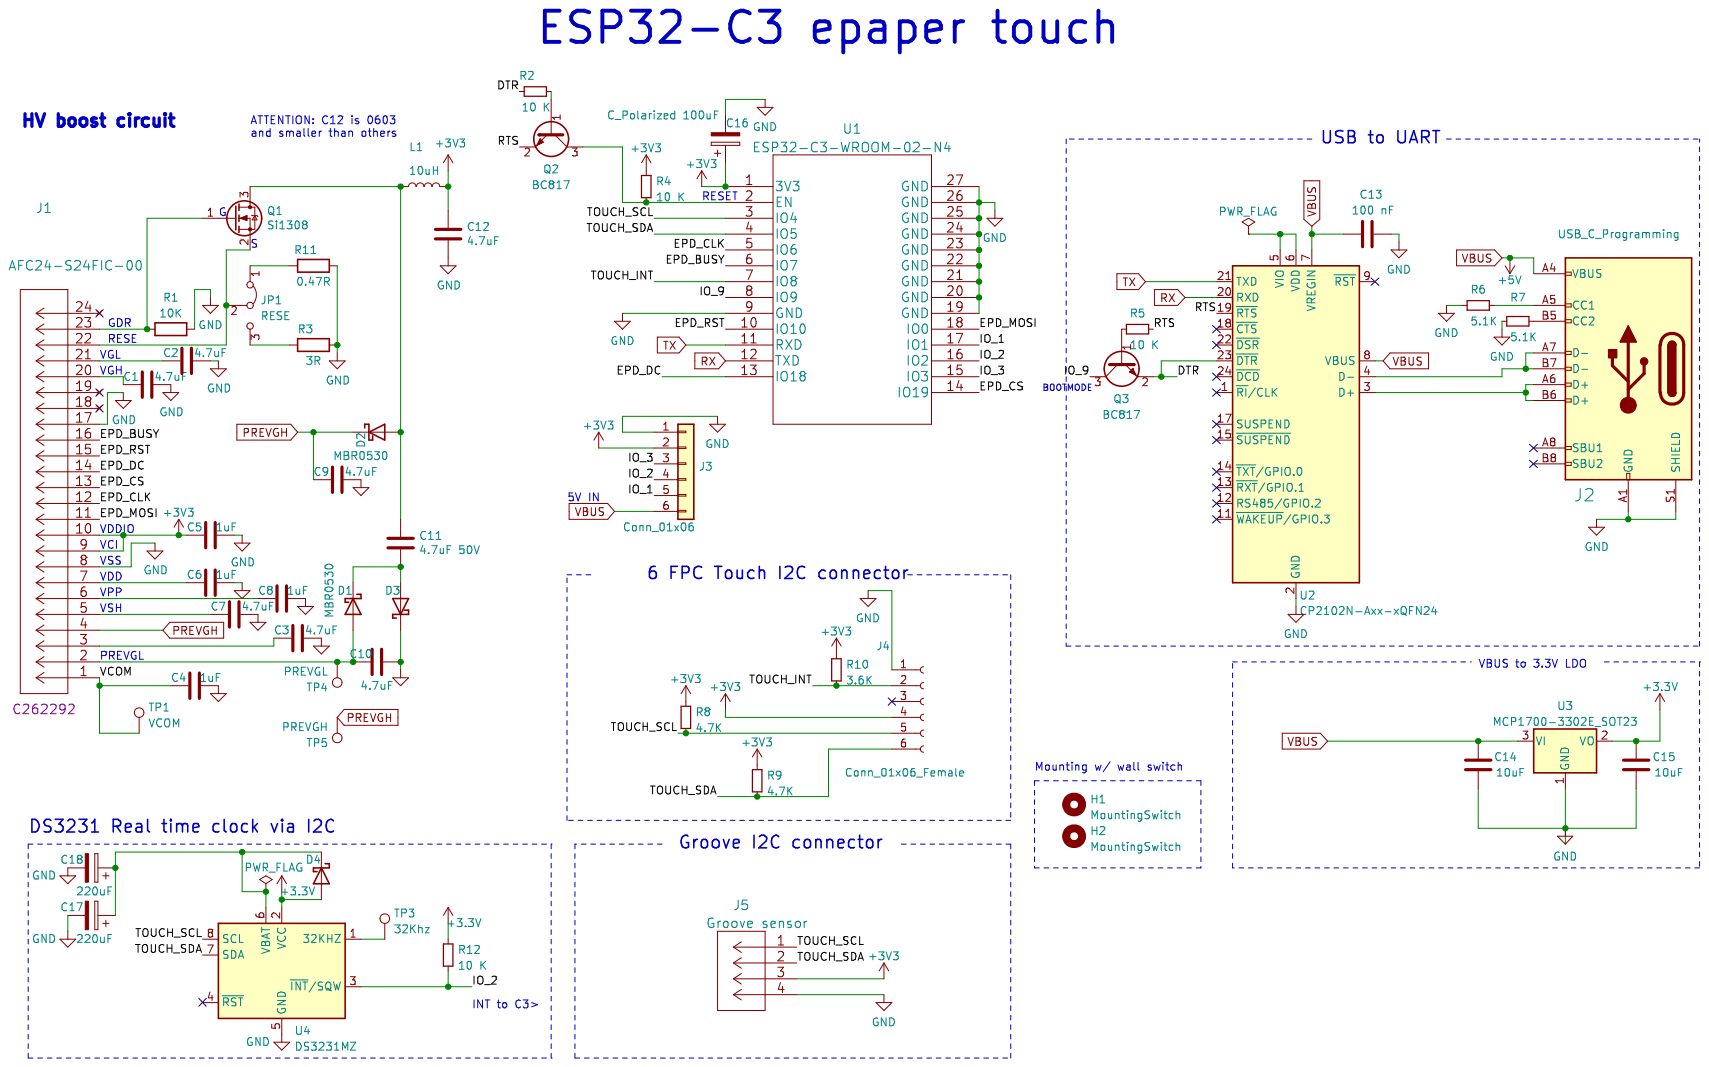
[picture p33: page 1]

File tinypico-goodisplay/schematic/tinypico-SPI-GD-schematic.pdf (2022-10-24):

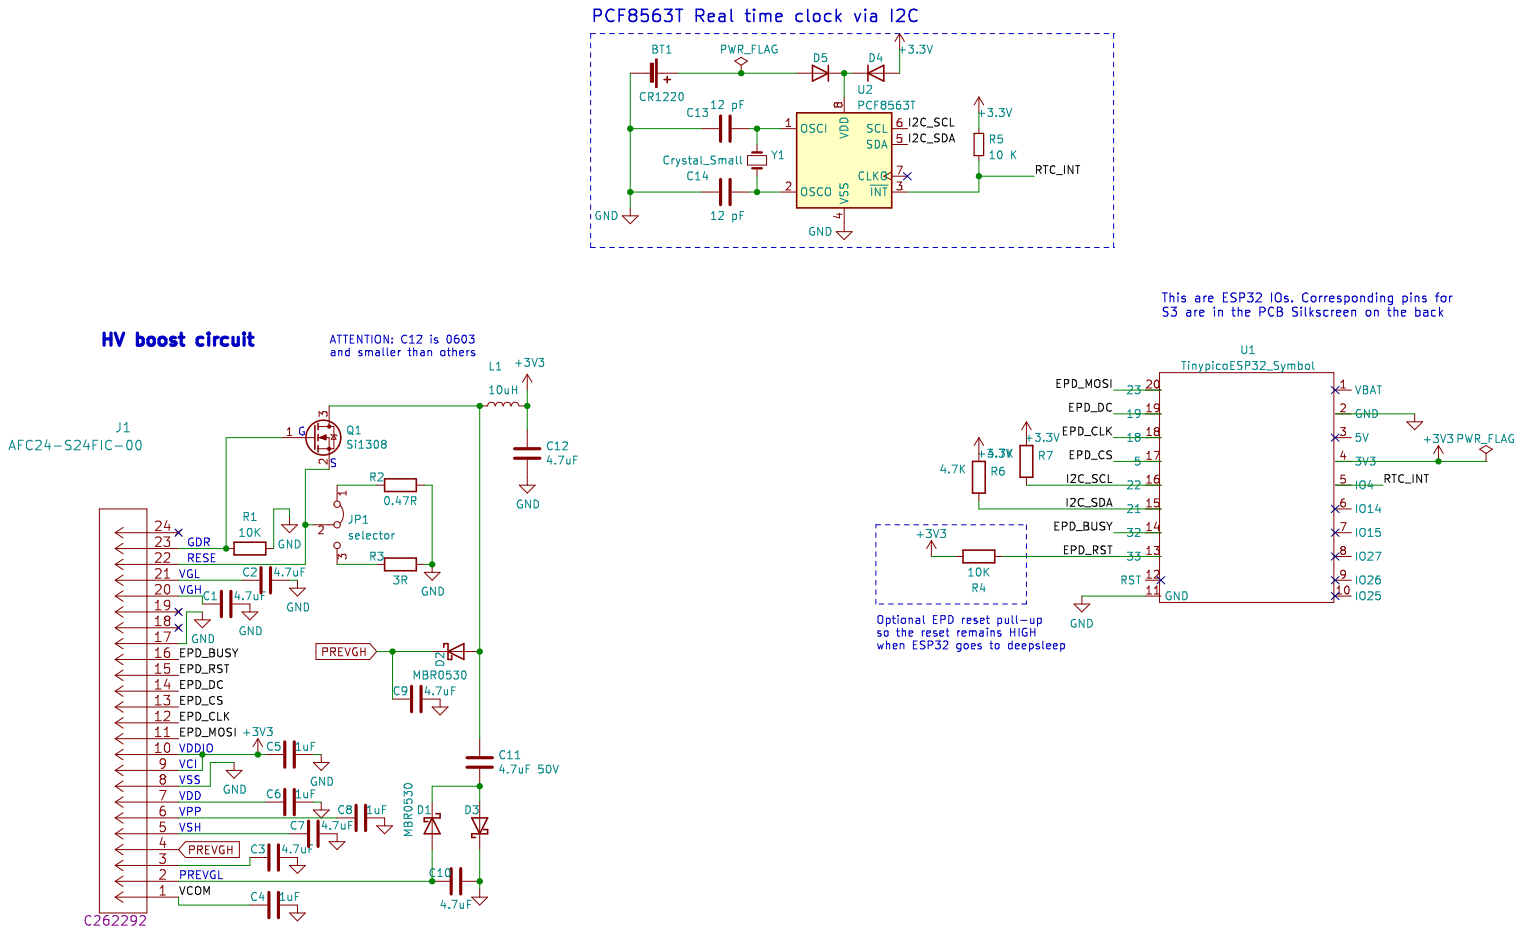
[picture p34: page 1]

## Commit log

2022-03-19 Move out RST from IO21->32
    [PLogic-SPI-HAT.kicad_pcb, PLogic-SPI-HAT.kicad_sch]
2022-03-20 Bump uc81156 adapter to REV 1.1, clean up old GBR
    [BOM.csv, PLogic-SPI-HAT.kicad_pcb, PLogic-SPI-HAT.kicad_sch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]
2022-03-20 Start goodisplay SPI adapter
    [tinypico-goodisplay.kicad_pcb, tinypico-goodisplay.kicad_sch]
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2022-03-20 Update netlist and schematic
    [FH12-24S-0.5SH_55_.step, tinypico-goodisplay.kicad_sch]
2022-03-20 SCH works, dont touch
    [tinypico-goodisplay.kicad_sch]
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2022-03-21 Min. VIA when PCB is 2 layer is 0.6mm
    [tinypico-goodisplay.kicad_pcb]
2022-03-25 Add LCSC part Nr
    [tinypico-goodisplay.kicad_pcb, tinypico-goodisplay.kicad_sch]
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2022-04-08 Goodisplay FPC connector pins are on the TOP
    [tinypico-goodisplay.kicad_sch]
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2022-04-11 Do not exclude C8 from POS files
    [tinypico-goodisplay.kicad_pcb, tinypico-goodisplay.kicad_sch]
2022-05-13 Capacitor btw. diodes is 4.7uF not 470nF
    [tinypico-goodisplay.kicad_sch]
2022-09-23 Lilygo S3 to 33 pin adapter idea
    [S3-44-to-33-FPC.kicad_pcb, S3-44-to-33-FPC.kicad_sch, XF2M_3315_1A.step]
2022-09-27 Test with upside down footprint
    [S3-44-to-33-FPC.kicad_pcb, S3-44-to-33-FPC.kicad_sch]
2022-09-27 Partial update to larger PCB (31 mm)
    [S3-44-to-33-FPC.kicad_pcb, S3-44-to-33-FPC.kicad_sch]
2022-09-27 Update to a larger PCB
    [S3-44-to-33-FPC.kicad_pcb]
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2022-10-16 #1 Route HEADER connector
    [S3-44-to-33-FPC.kicad_pcb, S3-44-to-33-FPC.kicad_sch]
2022-10-16 #1 Add 15 V neg & pos correctly + FIELD
    [S3-44-to-33-FPC.kicad_pcb, S3-44-to-33-FPC.kicad_sch]
2022-10-16 #1 Reroute after finding out pins are wrongly set
    [S3-44-to-33-FPC.kicad_pcb, S3-44-to-33-FPC.kicad_sch]
2022-10-16 #1 Add components & 3d
    [adapter-Lilygo-3D.stl, axe644124.stp]
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2022-10-20 Add optional EPD_RST pullup to 3V3
    [tinypico-goodisplay.kicad_pcb, tinypico-goodisplay.kicad_sch]
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2022-10-22 #2 Add PCF8563 RTC
    [XTAL_FC-135_EPS.step, tinypico-goodisplay.kicad_pcb, tinypico-goodisplay.kicad_sch]
2022-10-22 Correct routing, remove RTC TP1
    [tinypico-goodisplay.kicad_pcb, tinypico-goodisplay.kicad_sch]
2022-10-23 #2 Add CR1220 as optional RTC backup
    [CR1220-2.step, tinypico-goodisplay.kicad_pcb, tinypico-goodisplay.kicad_sch]
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2022-10-27 Add S3 AXE to 33 pin FPC Schematics
    [S3-44-to-33-FPC-B_Cu.gbl, S3-44-to-33-FPC-B_Mask.gbs, S3-44-to-33-FPC-B_Paste.gbp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]
2022-10-29 Add GD tinypico BOM + POS files
    [bom.xlsx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]
2022-11-09 Add latest version of GoodDisplay SPI adapter
    [tinypico-goodisplay.kicad_pcb]
2022-11-09 Update AXE adapter images
    [S3-44-to-33-FPC.kicad_sch]
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2022-12-15 #3 Start adding Schematic + PCB
    [220AC-mini-C3-board.kicad_pcb, 220AC-mini-C3-board.kicad_sch, 5SP_Axial_BEL.step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]
2022-12-16 Relabeling Sylkscreen with SPI pins
    [tinypico-goodisplay.kicad_pcb]
2022-12-16 #3 Modifications after father analysis
    [220AC-mini-C3-board.kicad_pcb, 220AC-mini-C3-board.kicad_sch, CAP_CC1808_YAG.step]
2022-12-22 #3 Ready for fabrication
    [0443Series_LTF.step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]
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2022-12-23 1st version, no relay still C3 with touch #3
    [AP22802AW5-7.step, C3-27-epaper-touch.kicad_pcb, CAP_CC1808_YAG.step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]
2022-12-24 #3 Latch relay will be on 220AC PCB
    [220AC-mini-C3-board.kicad_pcb, 220AC-mini-C3-board.kicad_sch, C3-27-epaper-touch.kicad_pcb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]
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2022-12-24 #3 Update both boards to match extra IO pins
    [220AC-mini-C3-board.kicad_pcb, 220AC-mini-C3-board.kicad_sch, C3-27-epaper-touch.kicad_pcb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]
2022-12-25 #3 Add Cap at 3.3V entry of C3
    [C3-27-epaper-touch.kicad_pcb, C3-27-epaper-touch.kicad_sch]
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2022-12-30 Further enhancements for #3 wall switch mounting holes
    [220AC-mini-C3-board.kicad_pcb, 220AC-mini-C3-board.kicad_sch, C3-27-epaper-touch.kicad_pcb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]
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2023-01-02 #3 First v1.0 ready after tests for fabrication
    [C3-27-BOM.csv, C3-27-BOM.xlsx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]
2023-01-05 Minor corrections
    [C3-27-BOM.xlsx, C3-27-epaper-touch.kicad_pcb, C3-27-epaper-touch.kicad_sch]
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2023-01-05 #3 220 AC to 3.3VDC redesign to fit in wall switch
    [220AC-mini-C3-board.kicad_pcb, 220AC-mini-C3-board.kicad_sch, C3-27-epaper-touch.kicad_pcb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]
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2023-01-08 #3 Both PCBs C3 controller & 220AC to 3.3VDC sent to fabrication
    [220AC-mini-C3-board-B_Cu.gbl, 220AC-mini-C3-board-B_Mask.gbs, 220AC-mini-C3-board-B_Paste.gbp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]
2023-01-19 #3 Fix BOOTMODE chg IO0->reroute->IO9
    [C3-27-epaper-touch.kicad_sch]
2023-01-19 #3 Update PCB Routing after IO9 BOOT mode issue + IO8 resistance update
    [C3-27-epaper-touch.kicad_pcb]
2023-01-21 #3 Reroute properly. Add 5V connected to VBUS ext. pin
    [C3-27-epaper-touch.kicad_pcb, C3-27-epaper-touch.kicad_sch]
2023-01-21 #3 Close this for Rev 1.1 220AC still has transistor Issues that need revision
    [220AC-mini-C3-board.kicad_pcb, 220AC-mini-C3-board.kicad_sch, C3-27-epaper-touch.kicad_pcb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]
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2023-01-27 #3 After silk correction should pass DRC
    [220AC-mini-C3-board.kicad_pcb]
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2023-01-31 #3 Remove GND pane from Switch area. Thx @Leone25
    [220AC-mini-C3-board.kicad_pcb, C3-27-epaper-touch.kicad_pcb]
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2023-02-08 #6 correct CP2102 schematic
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2023-02-10 #6 Add release 1.0 routing DRC still not done
    [154-watch.kicad_pcb, 154-watch.kicad_sch, Button_SKRKAH.step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]
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2023-02-11 Bring to 220uF x 2 the RTC backup battery
    [C3-27-epaper-touch.kicad_pcb, C3-27-epaper-touch.kicad_sch]
2023-02-12 Last silk corrections for 1.1
    [C3-27-epaper-touch.kicad_pcb, C3-27-epaper-touch.kicad_sch]
2023-02-13 Correct silkscreen and center mount H
    [C3-27-epaper-touch.kicad_pcb]
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2023-02-14 C3 update: C5 is a filtering CAP for epaper driver, place it closer
    [C3-27-epaper-touch.kicad_pcb]
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2023-04-13 #6 update 1.54" PCB to match sample sent by GOODISPLAY
    [154-watch.kicad_pcb, 154-watch.kicad_sch]
2023-04-13 #6 RTC errors fixed
    [154-watch.kicad_pcb]
2023-04-13 #6 Update touch PINUP (Was wrong)
    [154-watch.kicad_pcb, 154-watch.kicad_sch]
2023-04-14 #6 Add a pull-down to power switch Q4
    [154-watch.kicad_pcb, 154-watch.kicad_sch]
2023-04-15 Fix DRC 1.54 DRC
    [154-watch.kicad_pcb]
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2023-04-18 Add some test points in case UART works incorrectly https://github.com/martinberlin/H-spi-adapters/issues/9
    [154-watch.kicad_pcb, 154-watch.kicad_sch]
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2023-04-22 First draft of LCD controller, non DRC val #10
    [154-watch.kicad_sch, CP2102N-A01-GQFN20R.step, CR1220-2.step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]
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2023-04-23 #10 Rel 1.0 is ready for peer review
    [BOM.xlsx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]
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2023-04-24 #10 Remove R3 since SW3 has a pull-up in place
    [BOM.xlsx, bom.csv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]
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2023-04-25 C3 cheaper WROOM version (can be soldered manually)
    [ESP32-C3-WROOM-02-H4.step, sharp-lcd-128x128.kicad_pcb, sharp-lcd-128x128.kicad_sch]
2023-05-05 Sharp LCD prod. 1.0 and update to failed watch
    [154-watch.kicad_pcb, 154-watch.kicad_sch, BOM.xlsx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]
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2023-05-06 RST is pulled-up now to logic level 3V3
    [154-watch.kicad_pcb, 154-watch.kicad_sch]
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
